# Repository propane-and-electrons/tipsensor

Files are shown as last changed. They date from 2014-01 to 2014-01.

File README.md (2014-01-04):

tipsensor
---------

Flame effect tip sensor for emergency power cutoff, using an ATtiny84 and ADXL335 3-axis accelerometer. Compatible with ADXL335 SparkFun breakout board if you don't want to solder surface mount parts.

To use the tip sensor, place it (at any orientation) and press the "set" button. Connect the  power input to the load power and the output to the load device (such as solenoid valve). If the sensor changes orientation, it will disable the output power and deactivate the load device.

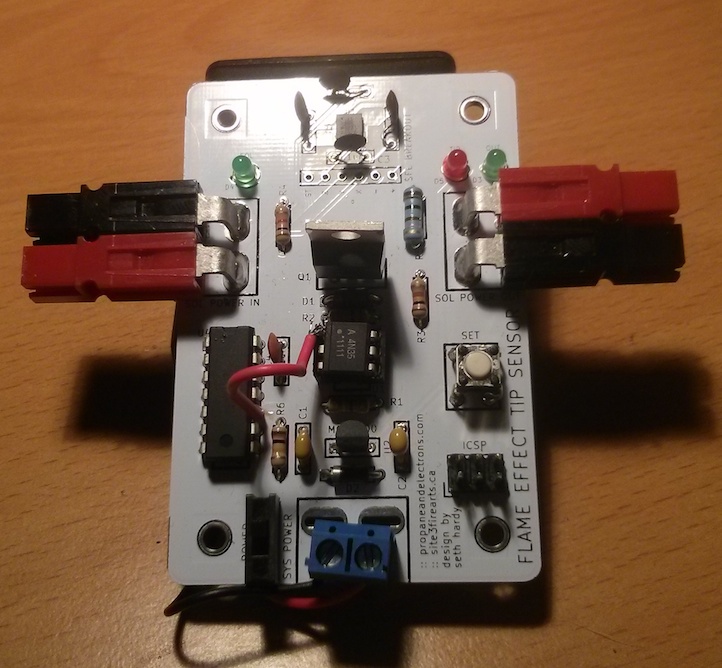
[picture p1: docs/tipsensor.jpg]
tipsensor photo


### Feature Summary

* Uses ATtiny84 microcontroller, Arduino compatible using [Arduino-Tiny](https://code.google.com/p/arduino-tiny/)
* Powered via external battery pack
* Programmable via ICSP header
* Tip or motion sensing via ADXL335 3-axis accelerometer
* Compatible with [SparkFun ADXL335 Breakout Board](https://www.sparkfun.com/products/9269)
* Footprints for screw terminals and Anderson Powerpole connectors
* Button to set the sensor's correct position
* LED indicators for system power and load power inputs, and power output

### Documents

* [Schematic](docs/tipsensor-schematic.pdf)
* [Bill of Materials](docs/tipsensor-BOM.csv)

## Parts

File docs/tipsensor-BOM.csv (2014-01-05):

Designator | Package | Quantity | Part | Digi-Key Part
C1,C2 | C2 | 2 | 1uF | 445-2884-ND
C7,C3,C5,C4,C6 | C2 | 5 | 0.1uF | 490-5388-ND
D1, D2 | D3 | 1 | 1N4004 | 641-1311-1-ND
D3, D4 | LED-3MM | 1 | 3mm LED (green) | 754-1603-ND
D5 | LED-3MM | 1 | 3mm LED (red) | 754-1606-ND
P1, P2, P3 | PP-2H-5MMSCREWTERM | 1 | 5mm screw terminal or Anderson Powerpole header | ED2600-ND
P4 | SIL-6 | 1 | SFE ADXL335 BOB | SparkFun SEN-09269
P5 | ICSP_3X2 | 1 | 3x2 pin header | 952-1895-ND
Q1 | TO220GDS_VERT | 1 | IRF510 | IRF510PBF-ND
R1 | R3 | 1 | 390 | 390QBK-ND
R2,R6 | R3 | 2 | 10k | 10KQBK-ND
R3,R4 | R3 | 2 | 1k | 1.0KQBK-ND
R5 | R3 | 1 | 100 | 100QBK-ND
SW1 | SIL-3 | 1 | SPDT switch | EG1903-ND
SW2 | SW-6MM-4PIN | 1 | 6mm pushbutton | SW400-ND
U1 | DIP-6__300 | 1 | 4N35 | 516-1557-5-ND
U2 | SIL-3 | 1 | MCP1700 | MCP1700-3302E/TO-ND
U3 | LFCSP_LQ_16 | 1 | ADXL335 | ADXL335BCPZ-ND
U4 | DIP-14__300 | 1 | ATTINY84 | ATTINY84A-PU-ND
XU1 | DIP-6 socket | 1 | 6DIP | A100203-ND

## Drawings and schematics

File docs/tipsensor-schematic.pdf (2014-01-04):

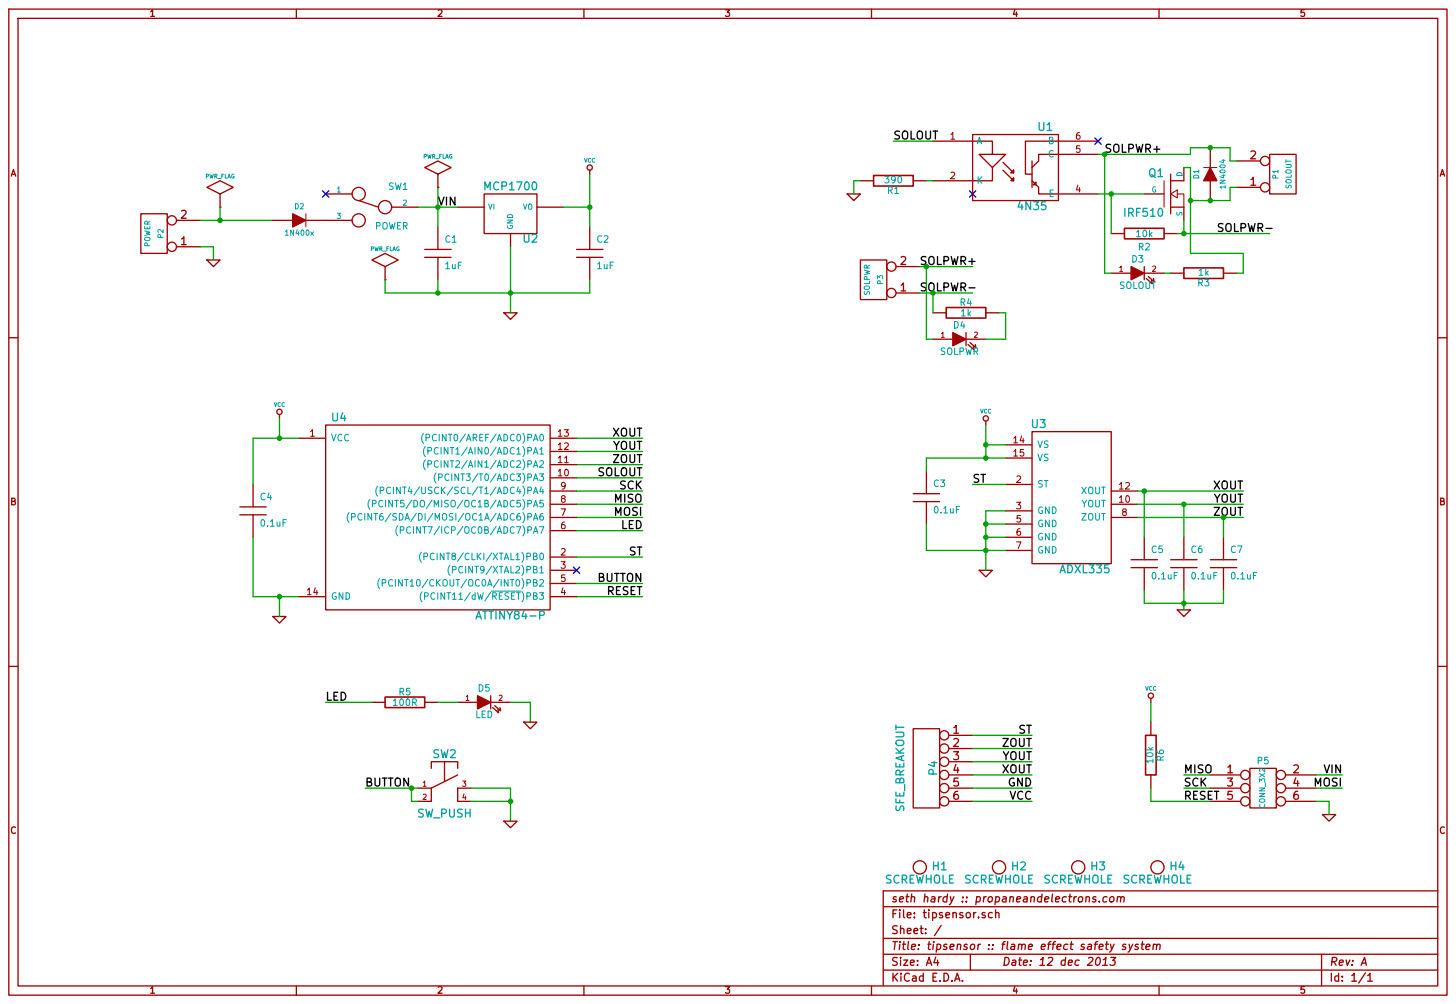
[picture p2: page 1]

seth hardy :: propaneandelectrons.com
File: tipsensor.sch
Sheet: /
Title: tipsensor :: flame effect safety system

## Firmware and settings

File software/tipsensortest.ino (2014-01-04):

#define OUT 7
#define XIN A0
#define YIN A1
#define ZIN A2
#define LED 3
#define BUTTON 0 // move to D2 pin5 for INT0

#define THRESHOLD 32

int x, y, z;
int xset, yset, zset;

void setup() {                
  pinMode(LED, OUTPUT);
  pinMode(OUT, OUTPUT);
  digitalWrite(LED, LOW);
  digitalWrite(OUT, LOW);
  digitalWrite(BUTTON, HIGH); //pullup
  
  analogReference(DEFAULT);
  xset = analogRead(XIN);
  yset = analogRead(YIN);
  zset = analogRead(ZIN);
  
}

void loop() {
  
  if( digitalRead(BUTTON) == LOW ) {
    digitalWrite(LED, HIGH);
    delay(500);
    digitalWrite(LED, LOW);
    xset = analogRead(XIN);
    yset = analogRead(YIN);
    zset = analogRead(ZIN);
  }
  
  x = analogRead(XIN);
  y = analogRead(YIN);
  z = analogRead(ZIN);
  
  if( (abs(xset - x) > THRESHOLD) || (abs(yset - y) > THRESHOLD) || (abs(zset - z) > THRESHOLD) ) {
    digitalWrite(LED, HIGH);
    digitalWrite(OUT, LOW);
  }
  else {
    digitalWrite(LED, LOW);
    digitalWrite(OUT, HIGH);
  }
    
    
}

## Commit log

2013-10-26 initial checkin
    [tipsensor.brd, tipsensor.sch]
2013-10-28 adding measurements in comments layer
    [tipsensor.brd]
2013-12-12 fixing a bunch of problems after first prototype build
    [tipsensor.brd, tipsensor.sch]
2014-01-04 updating documentation
    [tipsensor-BOM.csv]
2014-01-04 adding tip sensor test
2014-01-04 forgot one item
    [tipsensor-BOM.csv]
2014-01-05 forgot socket
    [tipsensor-BOM.csv]
2014-01-16 changing footprint name
    [tipsensor.brd]
